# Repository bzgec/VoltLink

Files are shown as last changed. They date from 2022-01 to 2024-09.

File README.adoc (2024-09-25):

= VoltLink™
:toc:
:sectnums:
:sectnumlevels: 4

* Current version: *0.1*
* link:./CHANGELOG.adoc[Changelog]

To enable TX and RX LEDs use `cp210x-cfg`.
1. Go to `cp210x-cfg` folder
2. `make`
3. `./cp210x-cfg -L 1`

'''

== Original author's README - ish

link:https://github.com/voltlog/VoltLink[Original repository]

VoltLink™ is a USB to serial adapter board based on the popular CP2102N chip with built-in ESP32 auto-reset circuitry.
When compared to the cheap modules you can get from Aliexpress this adapter is reliable & flexible at the same time.
Reliable because it's based on a well known usb to serial adapter chip sourced from a known supplier and flexible because you have the ESP32 IO & EN pin auto-reset circuit built-in so there is no need to implement this on the target board.

You have the option of connecting through the VoltLink connector which is a JST-SH 1.0mm pitch 6 pin connector that saves space on the target board or via standard 0.1 inch pin header.

If you would like to order one of these adapters ready assembled, check out my link:https://www.tindie.com/products/23076/[Tindie store].

More info about this project in:

* link:https://www.youtube.com/watch?v=bfN77jT1SVE[Voltlog #356 - VoltLink A Fancy USB Serial Adapter (ESP32 Programmer)].
* link:https://www.youtube.com/watch?v=roMjPoaFAZ8[Voltlog #357 - A fatal error occurred: Failed to connect to ESP32]
* link:https://www.youtube.com/watch?v=hDepAs7ljAk[Voltlog #396 - VoltLink™ revB CP2102N USB Serial Bridge & ESP32 Programmer]

== Automated exporting
=== Installation
==== KiBot
link:https://github.com/INTI-CMNB/kibot#installation-using-pip[Installation]:

* `pip install --no-compile kibot`
(on Windows you probably need to install it in `KiCad Command Prompt`)

* On Arch Linux you can install it with: `paru -S kibot-git`
** You may need to install `pcbdraw-git` in case of
`module 'pcbnew' has no attribute 'PLOTTEXTMODE_STROKE'` error
(try to run `pcbnew --version` to be sure that program runs correctly)
** You also may need to install `imagemagick`: `sudo pacman -S imagemagick`
** You also may need to install few `pip` packages: `pip install mistune pybars3 wand`

==== recordmydesktop
* Needed only if running `kibot -vvv`
* Arch Linux: `sudo pacman -S recordmydesktop`

== TODO

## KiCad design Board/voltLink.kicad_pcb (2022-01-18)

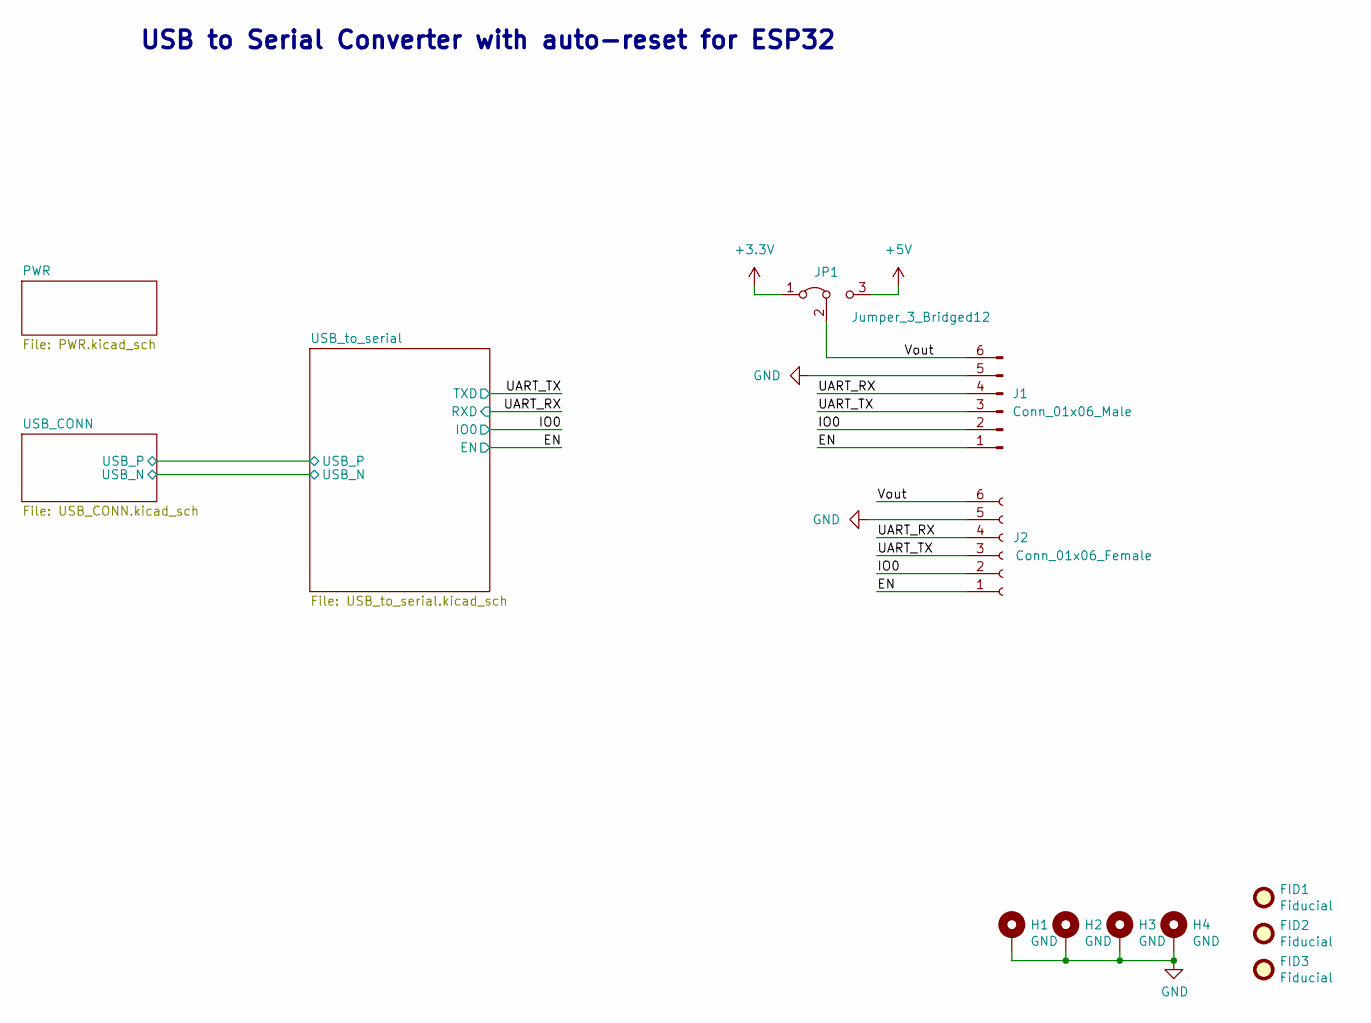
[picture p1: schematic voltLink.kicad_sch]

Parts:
FID1, FID2, FID3: Fiducial; Fiducial_0.5mm_Mask1mm
H1, H2, H3, H4: GND; MountingHole_2.5mm_Pad
J1: Conn_01x06_Male; PinHeader_1x06_P2.54mm_Horizontal
J2: Conn_01x06_Female; JST_SH_BM06B-SRSS-TB_1x06-1MP_P1.00mm_Vertical
JP1: Jumper_3_Bridged12; PinHeader_1x03_P2.54mm_Vertical

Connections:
+3V3: JP1.1 (A); also elsewhere on the board
+5V: JP1.3 (B); also elsewhere on the board
/EN: J1.1, J2.1; also elsewhere on the board
/IO0: J1.2, J2.2; also elsewhere on the board
/UART_RX: J1.4, J2.4; also elsewhere on the board
/UART_TX: J1.3, J2.3; also elsewhere on the board
/Vout: J1.6, J2.6, JP1.2 (C)
GND: H1.1, H2.1, H3.1, H4.1, J1.5, J2.5; also elsewhere on the board

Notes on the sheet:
USB to Serial Converter with auto-reset for ESP32

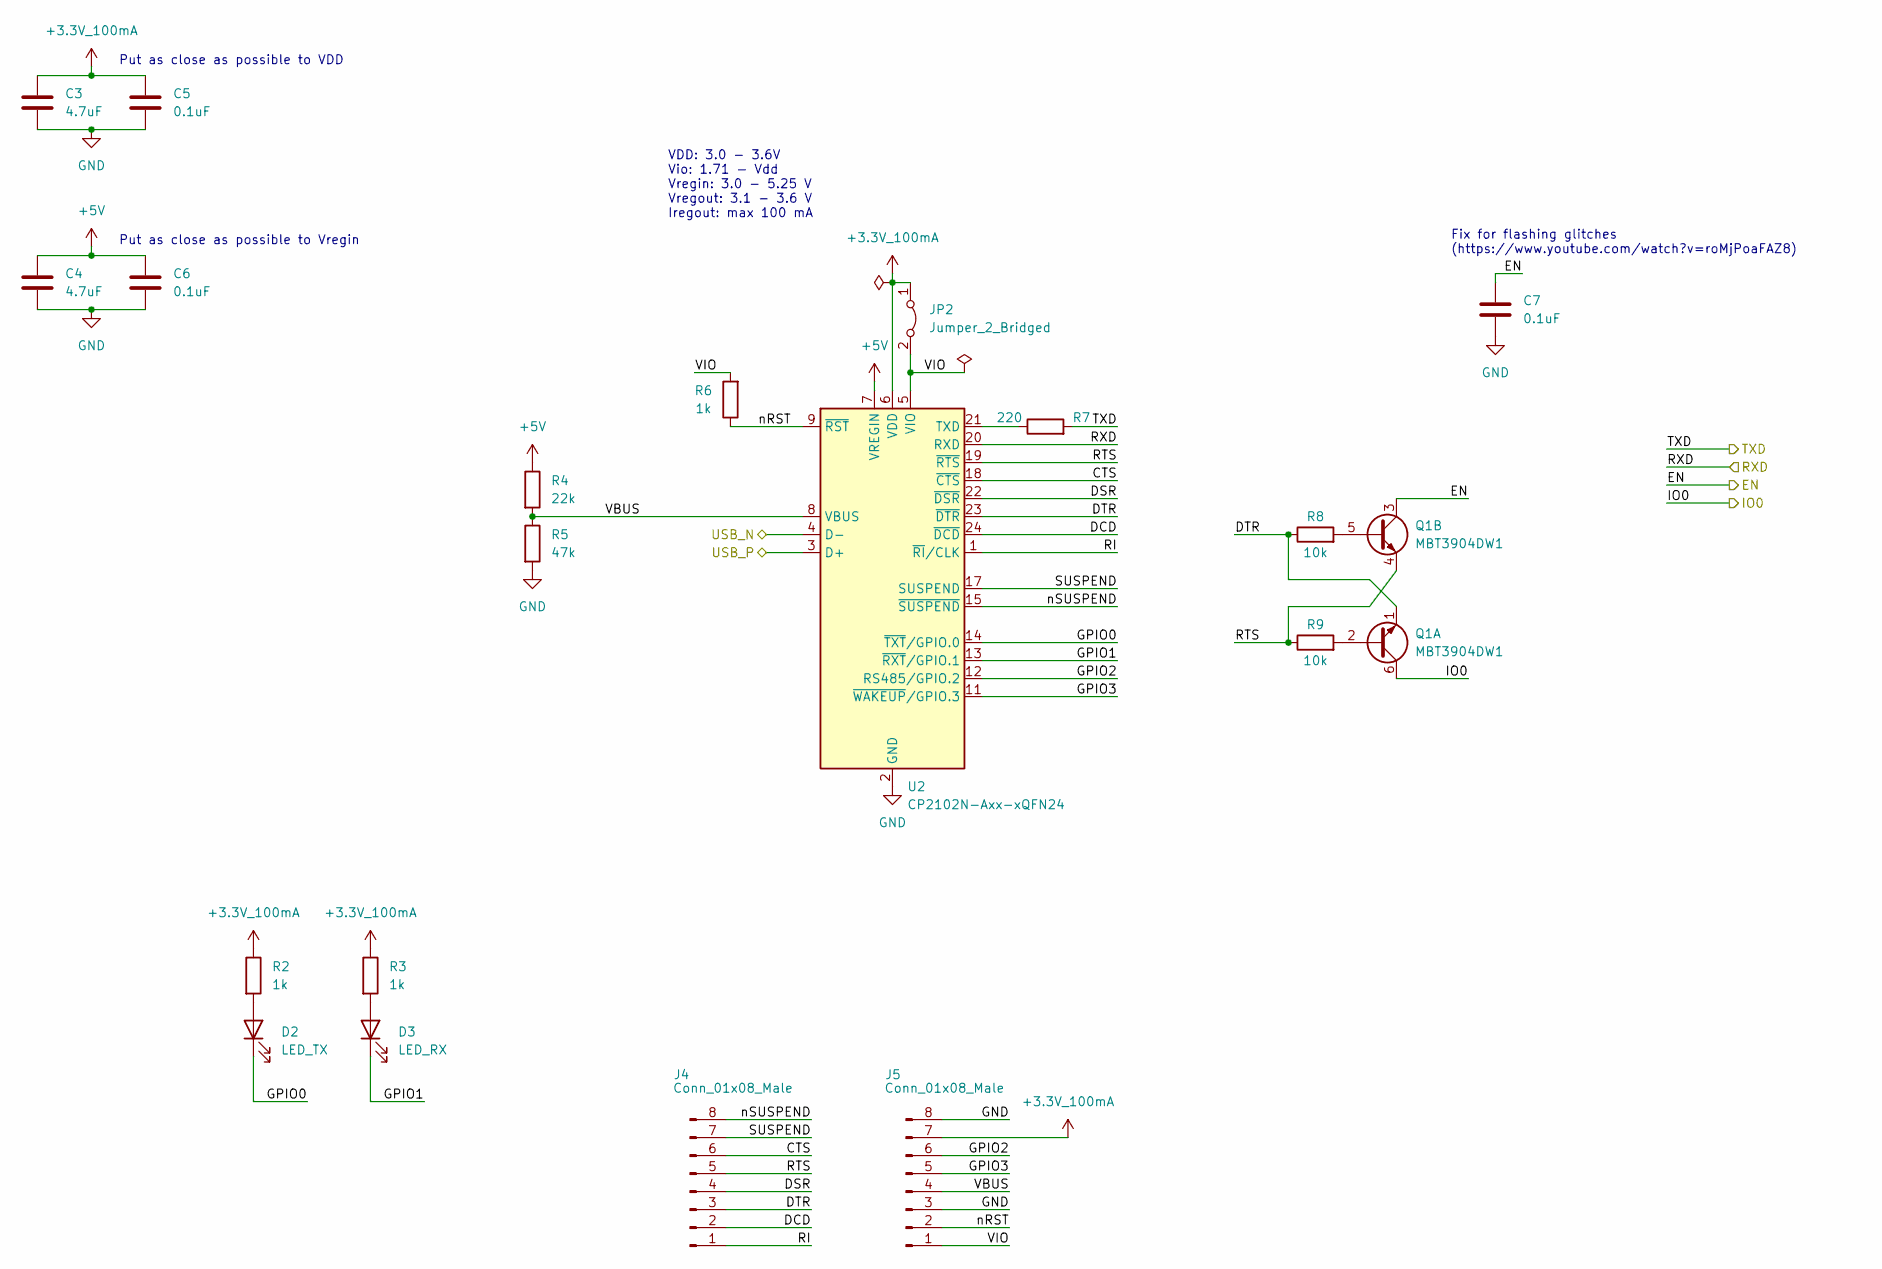
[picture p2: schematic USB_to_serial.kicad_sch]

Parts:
C3, C4: 4.7uF; C_0603_1608Metric
C5, C6, C7: 0.1uF; C_0603_1608Metric
D2: LED_TX; D_0603_1608Metric_Pad1.05x0.95mm_HandSolder
D3: LED_RX; D_0603_1608Metric_Pad1.05x0.95mm_HandSolder
J4, J5: Conn_01x08_Male; PinHeader_1x08_P2.54mm_Vertical
JP2: Jumper_2_Bridged; SolderJumper-2_P1.3mm_Bridged_RoundedPad1.0x1.5mm
Q1: MBT3904DW1; SOT-363_SC-70-6
R2, R3, R6: 1k; R_0603_1608Metric
R4: 22k; R_0603_1608Metric
R5: 47k; R_0603_1608Metric
R7: 220; R_0603_1608Metric
R8, R9: 10k; R_0603_1608Metric
U2: CP2102N-Axx-xQFN24; QFN-24-1EP_4x4mm_P0.5mm_EP2.6x2.6mm

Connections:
+3.3V_100mA: C3.1, C5.1, J5.7, JP2.1 (A), R2.1, R3.1, U2.6 (VDD)
+5V: C4.1, C6.1, R4.1, U2.7 (VREGIN); also elsewhere on the board
/EN: C7.1, Q1.3 (C2); also elsewhere on the board
/IO0: Q1.6 (C1); also elsewhere on the board
/UART_RX: U2.20 (RXD); also elsewhere on the board
/UART_TX: R7.2; also elsewhere on the board
/USB_CONN/USB_N: U2.4 (D-); also elsewhere on the board
/USB_CONN/USB_P: U2.3 (D+); also elsewhere on the board
/USB_to_serial/CTS: J4.6, U2.18 (~CTS)
/USB_to_serial/DCD: J4.2, U2.24 (~DCD)
/USB_to_serial/DSR: J4.4, U2.22 (~DSR)
/USB_to_serial/DTR: J4.3, Q1.1 (E1), R8.1, U2.23 (~DTR)
/USB_to_serial/GPIO0: D2.1 (K), U2.14 (~TXT/GPIO.0)
/USB_to_serial/GPIO1: D3.1 (K), U2.13 (~RXT/GPIO.1)
/USB_to_serial/GPIO2: J5.6, U2.12 (RS485/GPIO.2)
/USB_to_serial/GPIO3: J5.5, U2.11 (~WAKEUP/GPIO.3)
/USB_to_serial/RI: J4.1, U2.1 (~RI/CLK)
/USB_to_serial/RTS: J4.5, Q1.4 (E2), R9.1, U2.19 (~RTS)
/USB_to_serial/SUSPEND: J4.7, U2.17 (SUSPEND)
/USB_to_serial/VBUS: J5.4, R4.2, R5.1, U2.8 (VBUS)
/USB_to_serial/VIO: J5.1, JP2.2 (B), R6.2, U2.5 (VIO)
/USB_to_serial/nRST: J5.2, R6.1, U2.9 (~RST)
/USB_to_serial/nSUSPEND: J4.8, U2.15 (~SUSPEND)
GND: C3.2, C4.2, C5.2, C6.2, C7.2, J5.3, J5.8, R5.2, U2.2 (GND), U2.25 (GND); also elsewhere on the board
unnamed: D2.2 (A), R2.2
unnamed: D3.2 (A), R3.2
unnamed: Q1.2 (B1), R9.2
unnamed: Q1.5 (B2), R8.2
unnamed: R7.1, U2.21 (TXD)

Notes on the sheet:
VDD: 3.0 - 3.6V Vio: 1.71 - Vdd Vregin: 3.0 - 5.25 V Vregout: 3.1 - 3.6 V Iregout: max 100 mA
Put as close as possible to VDD
Fix for flashing glitches (https://www.youtube.com/watch?v=roMjPoaFAZ8)
Put as close as possible to Vregin

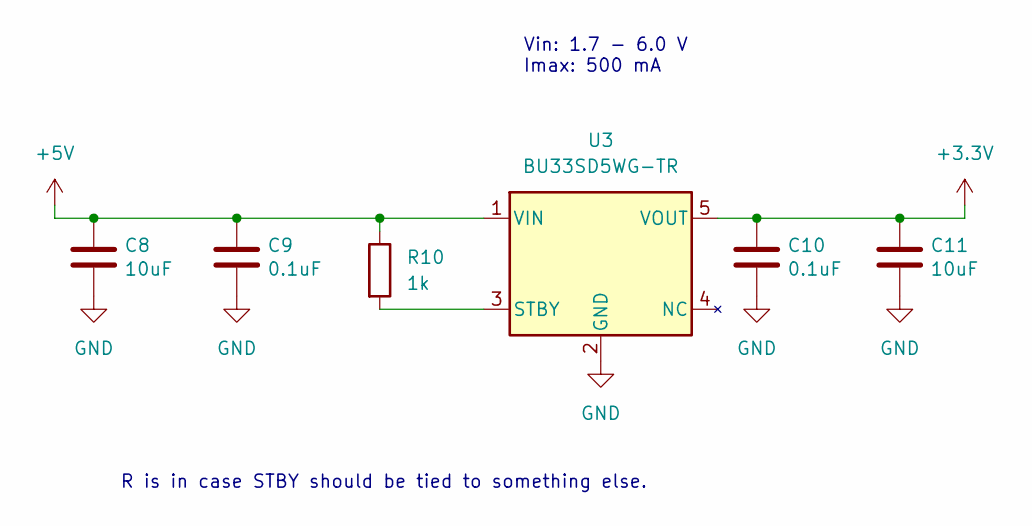
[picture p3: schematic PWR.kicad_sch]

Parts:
C8, C11: 10uF; C_0603_1608Metric
C9, C10: 0.1uF; C_0603_1608Metric
R10: 1k; R_0603_1608Metric
U3: BU33SD5WG-TR; SOT-23-5_HandSoldering

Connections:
+3V3: C10.1, C11.1, U3.5 (VOUT); also elsewhere on the board
+5V: C8.1, C9.1, R10.1, U3.1 (VIN); also elsewhere on the board
GND: C8.2, C9.2, C10.2, C11.2, U3.2 (GND); also elsewhere on the board
unnamed: R10.2, U3.3 (STBY)

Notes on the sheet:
Vin: 1.7 - 6.0 V Imax: 500 mA
R is in case STBY should be tied to something else.

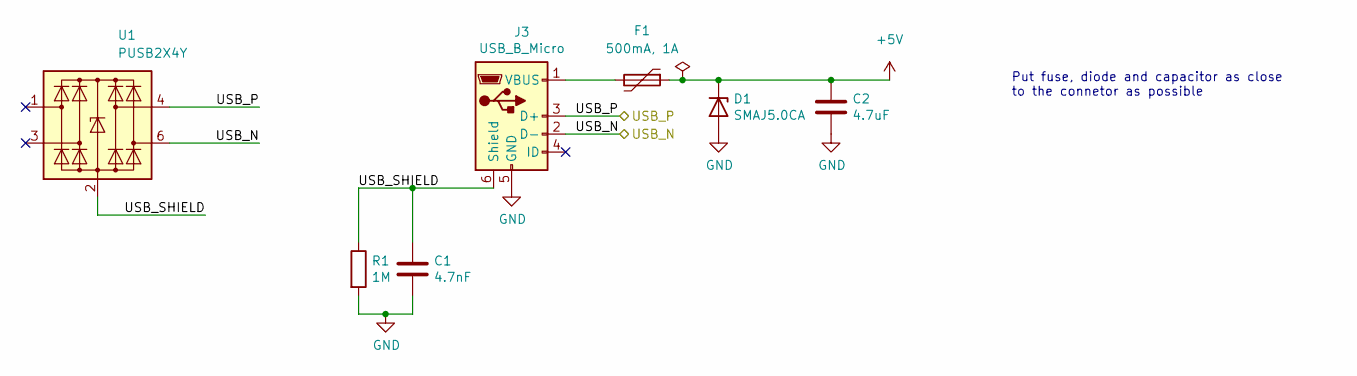
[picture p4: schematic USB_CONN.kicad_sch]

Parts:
C1: 4.7nF; C_0603_1608Metric
C2: 4.7uF; C_0603_1608Metric
D1: SMAJ5.0CA; D_SMA
F1: 500mA, 1A; Fuse_1206_3216Metric_Pad1.42x1.75mm_HandSolder
J3: USB_B_Micro; USB_Micro-B_Molex-105017-0001
R1: 1M; R_0603_1608Metric
U1: PUSB2X4Y; SOT-363_SC-70-6

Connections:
+5V: C2.1, D1.1 (K), F1.1; also elsewhere on the board
/USB_CONN/USB_N: J3.2 (D-), U1.6 (I/O4); also elsewhere on the board
/USB_CONN/USB_P: J3.3 (D+), U1.4 (I/O3); also elsewhere on the board
/USB_CONN/USB_SHIELD: C1.1, J3.6 (Shield), R1.1, U1.2 (GND)
GND: C1.2, C2.2, D1.2 (A), J3.5 (GND), R1.2; also elsewhere on the board
unnamed: F1.2, J3.1 (VBUS)

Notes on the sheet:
Put fuse, diode and capacitor as close to the connetor as possible

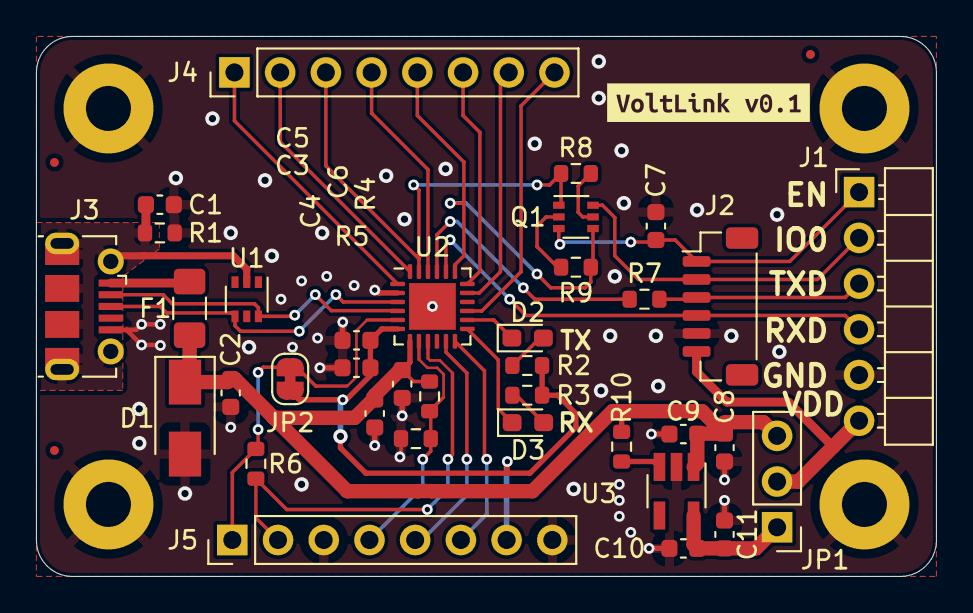
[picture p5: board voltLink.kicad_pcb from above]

Board: 2 copper layers, 50.0 x 30.0 mm, 44 parts (0 on the bottom side), 34 nets.

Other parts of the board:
kibuzzard-61E57FAE: G***; kibuzzard-61E57FAE

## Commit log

2022-01-17 Change project structure, board redesign
    [PWR.kicad_sch, USB_CONN.kicad_sch, USB_to_serial.kicad_sch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]
2022-01-17 Rename link to voltLink, fix KiBot export errors
    [voltLink.kicad_pcb, voltLink.kicad_sch]
2022-01-17 Add board name and version to PCB (kibuzzard)
    [voltLink.kicad_pcb]
2022-01-17 Move some silkscreen
    [voltLink.kicad_pcb]
2022-01-18 Change fiducial positions
    [voltLink.kicad_pcb]
2022-01-18 Uncomment pcbdraw and pdf_pcb_print in .kibot.yaml
2022-01-18 Add dpi option for pcbdraw in .kibot.yaml
2024-09-25 Add cp210x-cfg submodule to enable RX/TX LEDs

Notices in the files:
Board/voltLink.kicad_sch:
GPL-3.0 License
